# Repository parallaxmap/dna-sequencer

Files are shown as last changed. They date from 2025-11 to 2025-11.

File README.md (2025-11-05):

# DNA Sequencer
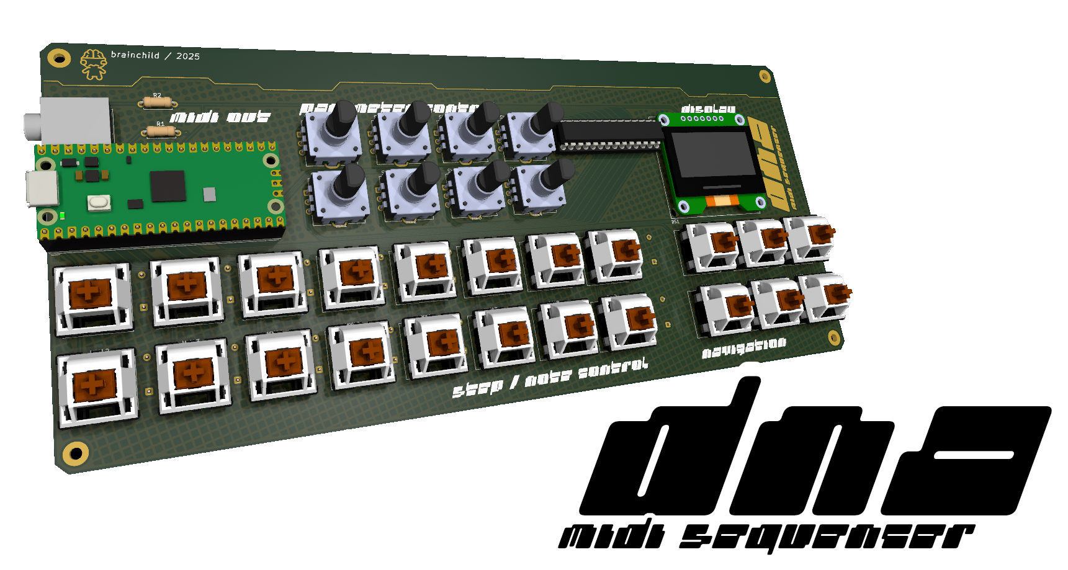
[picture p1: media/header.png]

A flexible MIDI sequencer powered by a Raspberry Pi Pico 2 (RP2350), inspired by sequencers found in the Korg Volca and Elektron boxes. Aims to be accessible, affordable, repurposable, and expandable.

## Current features
- RPi Pico 2 microcontroller, the brains of the sequencer
- MIDI output via 3.5mm TRS, or USB
- 16 keys for step editing, note input, or other custom macros
- 6 keys for navigation (get ready to menu dive!)
- 8 incremental encoders for CC/parameter adjustment and macros
- 128x64 1.3" OLED display
- All components are through-hole for easy soldering, and readily available

## Planned features
- 8 polyphonic tracks with different modes to facilitate various types of sequencing (e.g drum, chord, arp, euclidian, etc etc), can be assigned to any 16 MIDI channels
- 64 step sequencer with the ability to sequence 8 CC parameters, variable length, microtiming, and randomization/generation features
- 16 patterns with chaining

## Why'd you make this?
Currently the options for standalone hardware MIDI sequencers are either budget sequencers that do not have a vast featureset and, at least to myself, were limiting in terms of potential creativity, or more feature rich sequencers which cost a couple arms and legs. I wanted to make a device that would help bridge the gap between those two mountains and leverage the power of DIY & open source in order to create an accessible, affordable, repurposable, and expandable hardware sequencer. Additionally, this project serves as my first 100% serious hardware project, so all of the processes I learn throughout the journey of creating this device will be invaluable to me and whatever future endeavours lie before me... learning is fun!

## Images/Videos
PCB
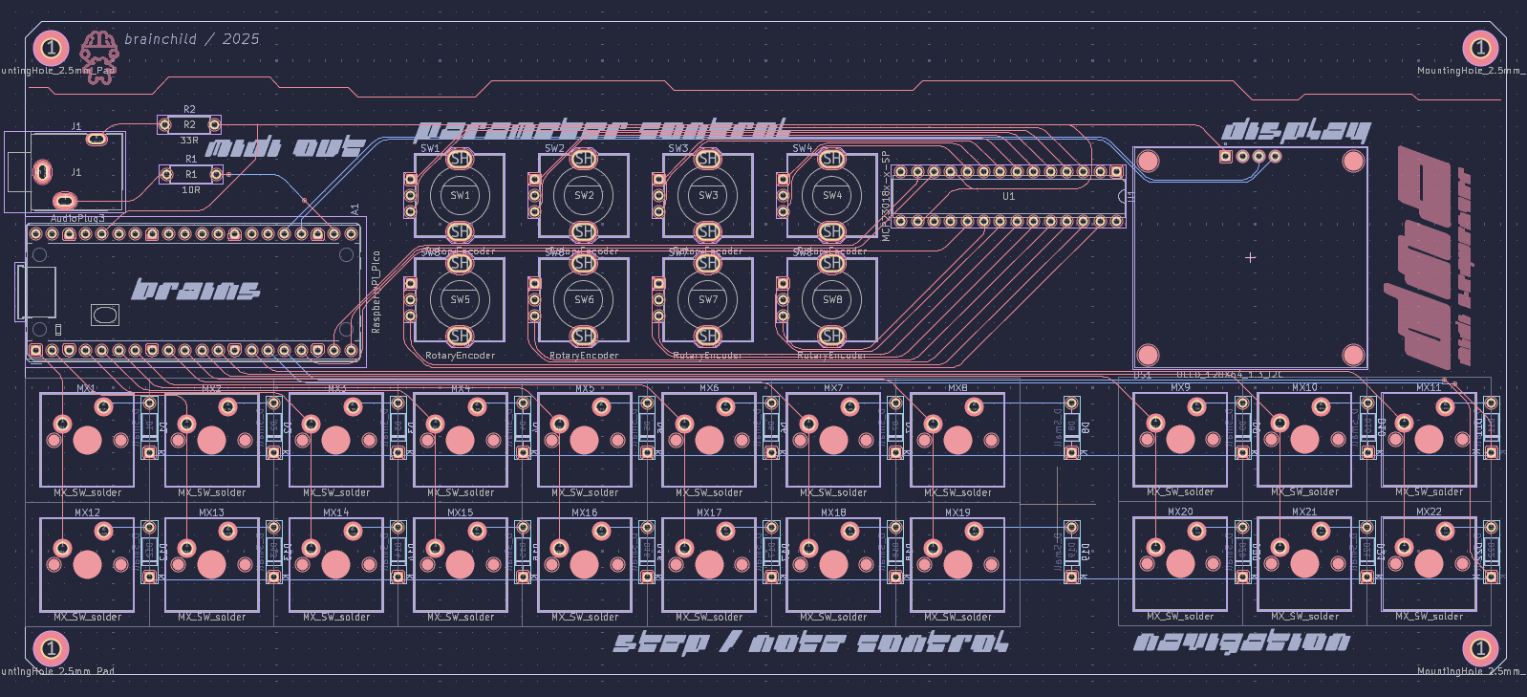
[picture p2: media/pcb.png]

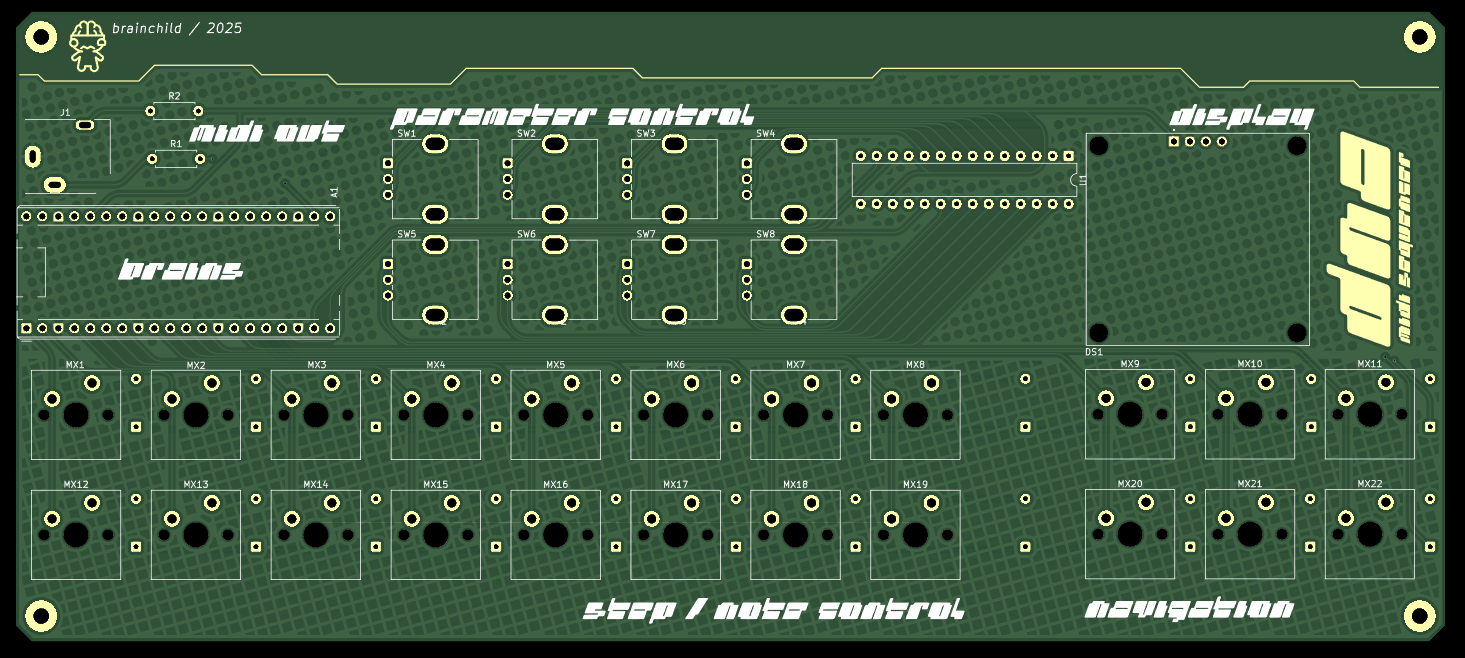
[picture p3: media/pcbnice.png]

Schematic
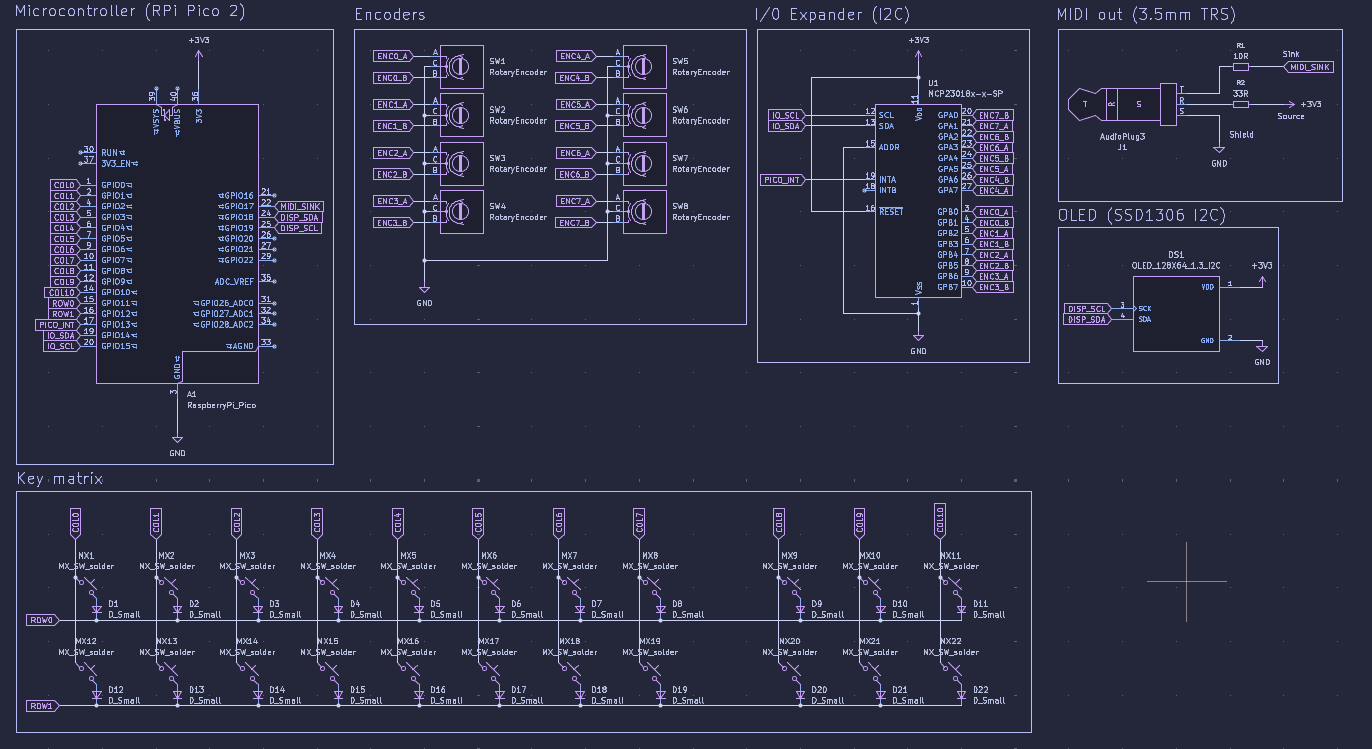
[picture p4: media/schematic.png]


## Bill of Materials

Choice of keycaps is up to you, as long as they're compatible with Cherry MX. You will also need a Micro USB cable for power and USB MIDI, and a 3.5 TRS to DIN converter for regular MIDI

|Item |Description |Quantity|Unit Price ($)|Total Price ($)|URL |Total |
|---|---|---|---|---|---|---|
|MBB02070C1009FCT00 |10 Ohm resistor |5 |$0.1346 |$0.6730 |https://www.lcsc.com/product-detail/C1364448.html |$0.6730|
|MBB02070C3309FCT00 |33 Ohm resistor |5 |$0.0748 |$0.3740 |https://www.lcsc.com/product-detail/C1366513.html |$1.05 |
|MCP23017-E/SP |I/O expander (I2C) |1 |$2.8158 |$2.8158 |https://www.lcsc.com/product-detail/C4992459.html |$3.86 |
|PEC12R-4120F-S0012 |Rotary encoder |8 |$1.8791 |$15.0328 |https://www.lcsc.com/product-detail/C143801.html |$18.90|
|SJ1-3533NG |3.5mm TRS jack |1 |$1.6565 |$1.6565 |https://www.lcsc.com/product-detail/C4992459.html |$20.55|
|KH-2.54FH-1X20P-H8.5 |Socket (20 pins) |5 |$0.1722 |$0.8610 |https://www.lcsc.com/product-detail/C2905423.html |$21.41|
| PH2.54-1X20P-H25 |Header (20 pins) |5 |$0.0488 |$0.2440 |https://www.lcsc.com/product-detail/C42431804.html |$21.66|
|IC-28P |DIP socket |17 |$0.0510 |$0.8670 |https://www.lcsc.com/product-detail/C5289491.html |$22.52|
|M3x10+6Cu |Standoffs |10 |$0.0387 |$0.3870 |https://www.lcsc.com/product-detail/C551322.html |$22.91|
|hexagon NUT M3 |Hex nut |100 |$0.0017 |$0.1700 |https://www.lcsc.com/product-detail/C133377.html |$23.08|
|1N4148 |Diodes |50 |$0.0116 |$0.5800 |https://www.lcsc.com/product-detail/C402212.html |$23.66|
|SH1106 |OLED display module |1 |$3.6800 |$3.6800 |https://www.aliexpress.com/item/1005006072386746.html|$27.34|
|MIDI DIN to 3.5mm TRS  |DIN/TRS converter cable |1 |$8.2000 |$8.2000 |https://www.aliexpress.com/item/1005009365055437.html|$35.54|
|Ugreen Micro USB Cable |Micro USB for microcontroller|1 |$2.6900 |$2.6900 |https://www.aliexpress.com/item/32391749504.html |$38.23|
|XDA Profile PBT Keycaps|1U keycaps (30pcs) |1 |$5.4100 |$5.4100 |https://www.aliexpress.com/item/1005005514406952.html|$43.64|
|11mm Potentiometer Knob|Knobs for encoders (10pcs) |1 |$2.1000 |$2.1000 |https://www.aliexpress.com/item/1005003991686731.html|$45.74|
|Gateron Switches KS9 |Key switch (30pcs) |1 |$12.9500 |$12.9500 |https://www.aliexpress.com/item/1005007474127225.html|$58.69|
|RPI Pico 2 |Microcontroller |1 |$8.9800 |$8.9800 |https://www.aliexpress.com/item/1005008201547951.html|$67.67|
|JLCPCB |PCB x 5 and shipping costs |1 |$24.42 |$24.42 | |$92.09|
|LCSC |LCSC shipping costs |1 |$8.84 |$8.84 | |$100.93|

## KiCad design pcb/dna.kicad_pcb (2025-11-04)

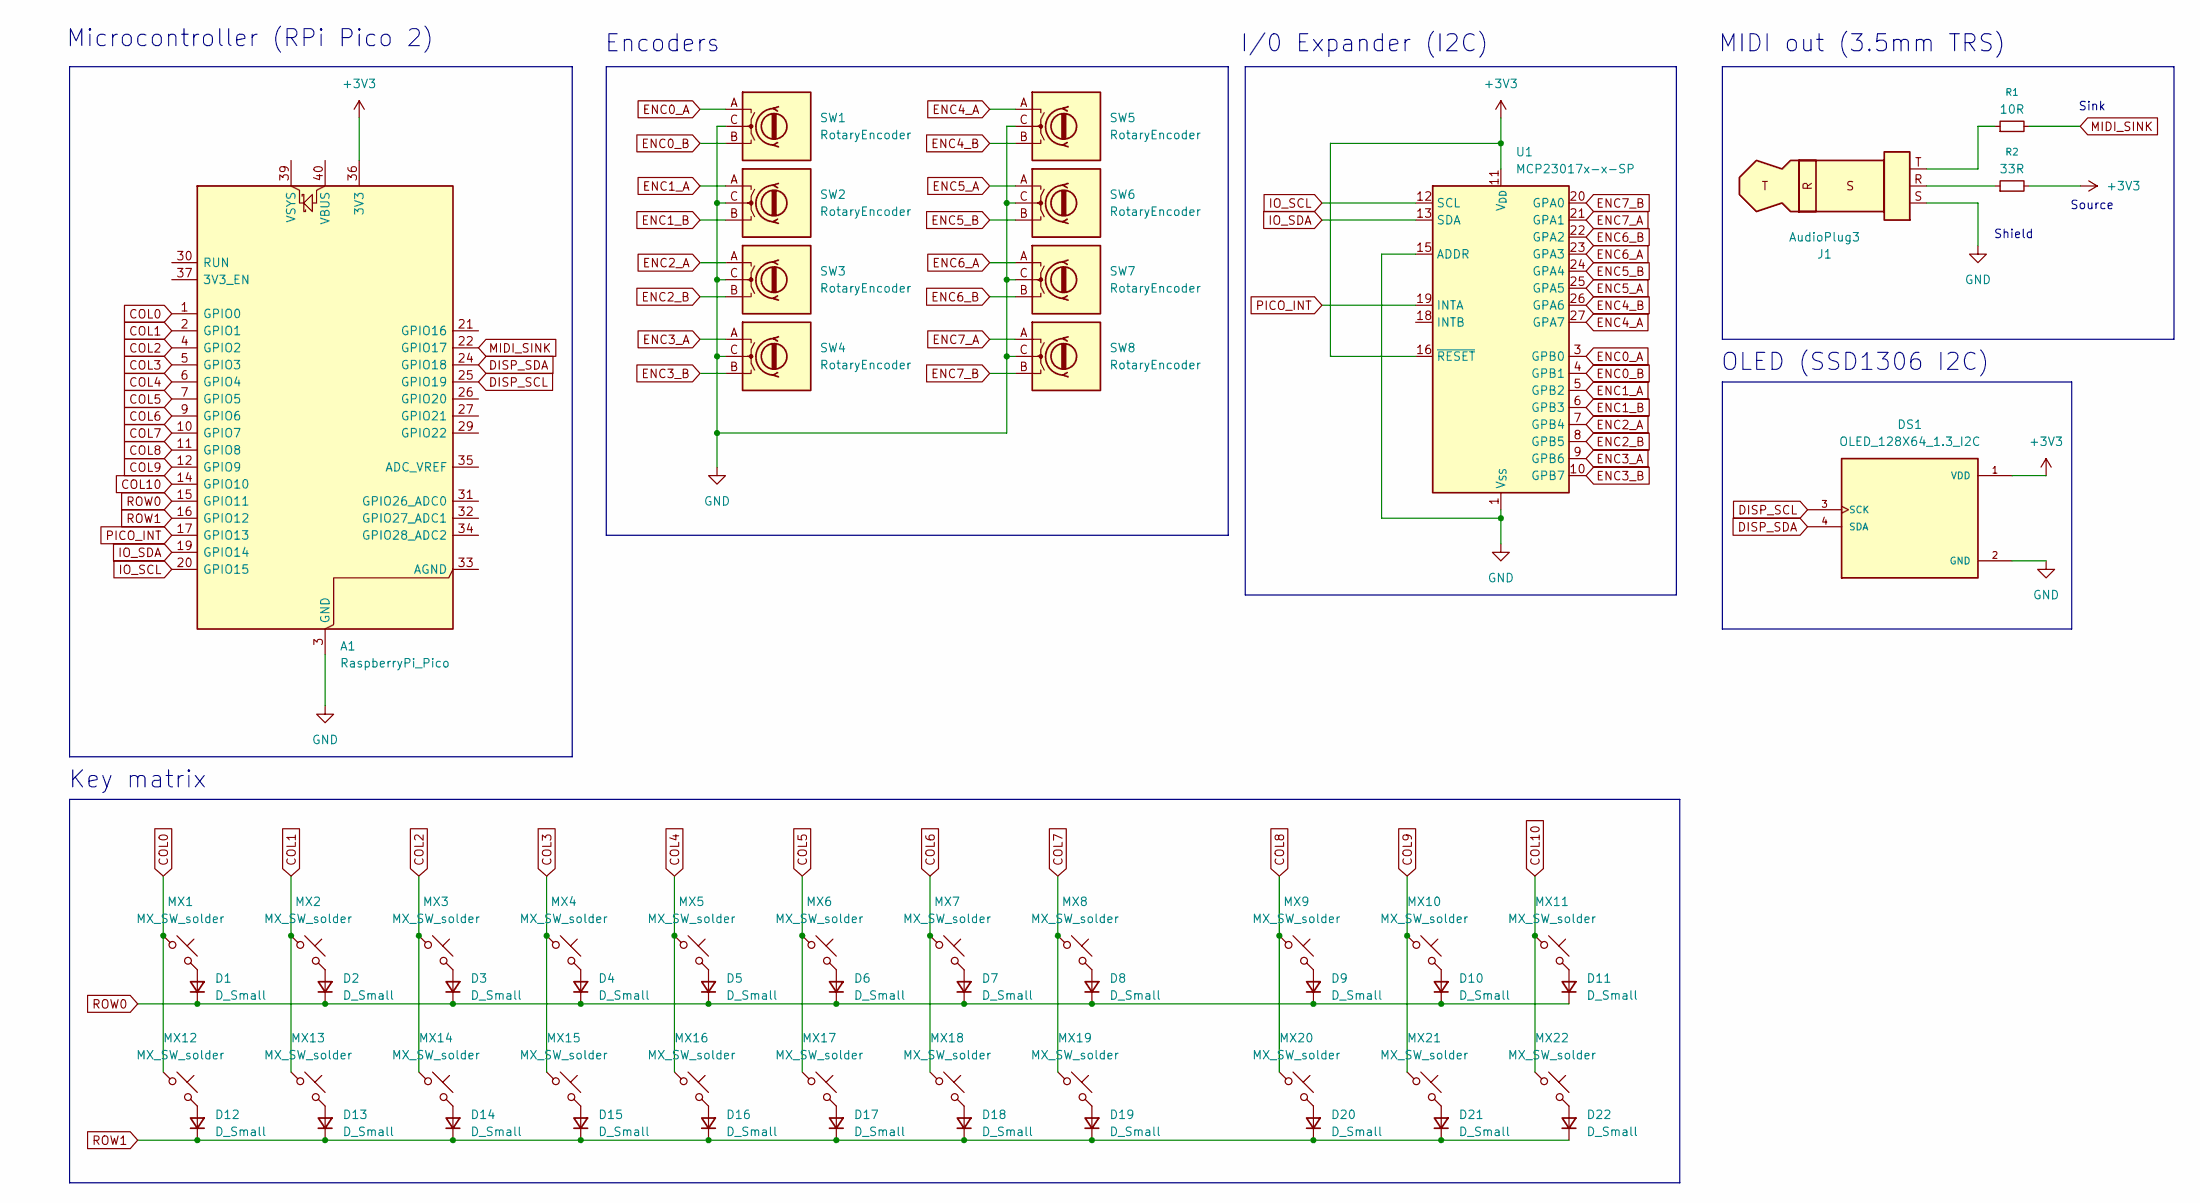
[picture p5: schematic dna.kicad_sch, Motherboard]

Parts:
A1: RaspberryPi_Pico; RaspberryPi_Pico_Common_THT
D1, D2, D3, D4, D5, D6, D7, D8, D9, D10, D11, D12, D13, D14, D15, D16, D17, D18, D19, D20, D21, D22: D_Small; D_DO-35_SOD27_P7.62mm_Horizontal
DS1: OLED_128X64_1.3_I2C; LCD_OLED_128X64_1.3_I2C; PARTREV NA
J1: AudioPlug3; Jack_3.5mm_CUI_SJ1-3533NG_Horizontal_CircularHoles
MX1, MX2, MX3, MX4, MX5, MX6, MX7, MX8, MX9, MX10, MX11, MX12, MX13, MX14, MX15, MX16, MX17, MX18, MX19, MX20, MX21, MX22: MX_SW_solder; SW_Cherry_MX_PCB_1.00u
R1: 10R; R_Axial_DIN0207_L6.3mm_D2.5mm_P7.62mm_Horizontal
R2: 33R; R_Axial_DIN0207_L6.3mm_D2.5mm_P7.62mm_Horizontal
SW1, SW2, SW3, SW4, SW5, SW6, SW7, SW8: RotaryEncoder; RotaryEncoder_Bourns_Vertical_PEC12R-3x17F-Sxxxx
U1: MCP23017x-x-SP; DIP-28_W7.62mm

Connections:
+3V3: A1.36 (3V3), DS1.1 (VDD), R2.2, U1.11 (V_{DD}), U1.16 (~RESET)
COL0: A1.1 (GPIO0), MX1.1, MX12.1
COL1: A1.2 (GPIO1), MX2.1, MX13.1
COL2: A1.4 (GPIO2), MX3.1, MX14.1
COL3: A1.5 (GPIO3), MX4.1, MX15.1
COL4: A1.6 (GPIO4), MX5.1, MX16.1
COL5: A1.7 (GPIO5), MX6.1, MX17.1
COL6: A1.9 (GPIO6), MX7.1, MX18.1
COL7: A1.10 (GPIO7), MX8.1, MX19.1
COL8: A1.11 (GPIO8), MX9.1, MX20.1
COL9: A1.12 (GPIO9), MX10.1, MX21.1
COL10: A1.14 (GPIO10), MX11.1, MX22.1
DISP_SCL: A1.25 (GPIO19), DS1.3 (SCK)
DISP_SDA: A1.24 (GPIO18), DS1.4 (SDA)
ENC0_A: SW1.A, U1.3 (GPB0)
ENC0_B: SW1.B, U1.4 (GPB1)
ENC1_A: SW2.A, U1.5 (GPB2)
ENC1_B: SW2.B, U1.6 (GPB3)
ENC2_A: SW3.A, U1.7 (GPB4)
ENC2_B: SW3.B, U1.8 (GPB5)
ENC3_A: SW4.A, U1.9 (GPB6)
ENC3_B: SW4.B, U1.10 (GPB7)
ENC4_A: SW5.A, U1.27 (GPA7)
ENC4_B: SW5.B, U1.26 (GPA6)
ENC5_A: SW6.A, U1.25 (GPA5)
ENC5_B: SW6.B, U1.24 (GPA4)
ENC6_A: SW7.A, U1.23 (GPA3)
ENC6_B: SW7.B, U1.22 (GPA2)
ENC7_A: SW8.A, U1.21 (GPA1)
ENC7_B: SW8.B, U1.20 (GPA0)
GND: A1.3 (GND), A1.8 (GND), A1.13 (GND), A1.18 (GND), A1.23 (GND), A1.28 (GND), A1.38 (GND), DS1.2 (GND), J1.S, SW1.C, SW2.C, SW3.C, SW4.C, SW5.C, SW6.C, SW7.C, SW8.C, U1.1 (V_{SS}), U1.15 (ADDR)
IO_SCL: A1.20 (GPIO15), U1.12 (SCL)
IO_SDA: A1.19 (GPIO14), U1.13 (SDA)
MIDI_SINK: A1.22 (GPIO17), R1.2
unnamed: D1.2 (A), MX1.2
unnamed: D2.2 (A), MX2.2
unnamed: D3.2 (A), MX3.2
unnamed: D4.2 (A), MX4.2
unnamed: D5.2 (A), MX5.2
unnamed: D6.2 (A), MX6.2
unnamed: D7.2 (A), MX7.2
unnamed: D8.2 (A), MX8.2
unnamed: D9.2 (A), MX9.2
unnamed: D10.2 (A), MX10.2
unnamed: D11.2 (A), MX11.2
unnamed: D12.2 (A), MX12.2
unnamed: D13.2 (A), MX13.2
unnamed: D14.2 (A), MX14.2
unnamed: D15.2 (A), MX15.2
unnamed: D16.2 (A), MX16.2
unnamed: D17.2 (A), MX17.2
unnamed: D18.2 (A), MX18.2
unnamed: D19.2 (A), MX19.2
unnamed: D20.2 (A), MX20.2
unnamed: D21.2 (A), MX21.2
unnamed: D22.2 (A), MX22.2
unnamed: J1.R, R2.1
unnamed: J1.T, R1.1
PICO_INT: A1.17 (GPIO13), U1.19 (INTA)
ROW0: A1.15 (GPIO11), D1.1 (K), D2.1 (K), D3.1 (K), D4.1 (K), D5.1 (K), D6.1 (K), D7.1 (K), D8.1 (K), D9.1 (K), D10.1 (K), D11.1 (K)
ROW1: A1.16 (GPIO12), D12.1 (K), D13.1 (K), D14.1 (K), D15.1 (K), D16.1 (K), D17.1 (K), D18.1 (K), D19.1 (K), D20.1 (K), D21.1 (K), D22.1 (K)

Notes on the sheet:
Key matrix
Sink
I/0 Expander (I2C)
Source
Microcontroller (RPi Pico 2)
MIDI out (3.5mm TRS)
OLED (SSD1306 I2C)
Encoders
Shield

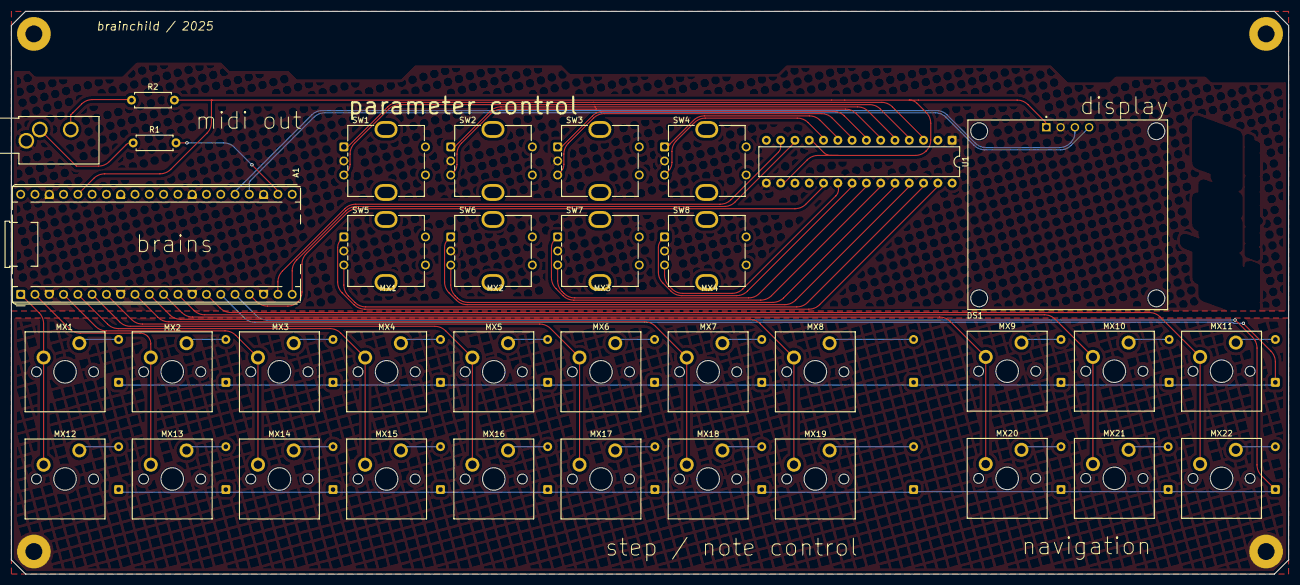
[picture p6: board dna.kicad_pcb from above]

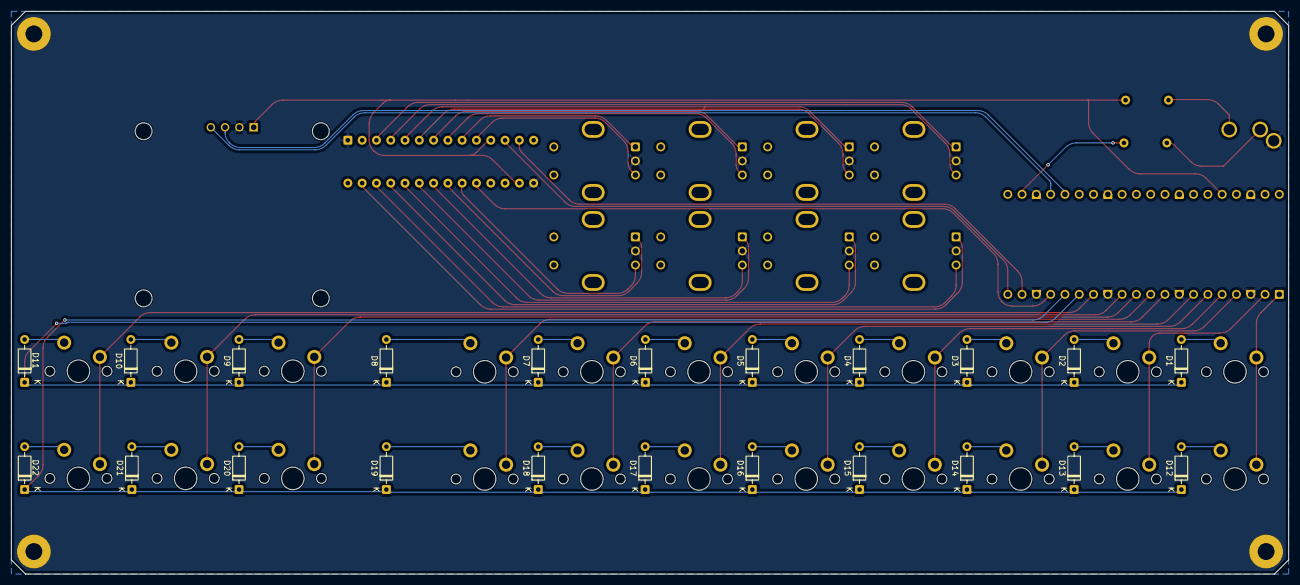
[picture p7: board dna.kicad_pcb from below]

Board: 2 copper layers, 227.0 x 100.0 mm, 58 parts (22 on the bottom side), 61 nets.

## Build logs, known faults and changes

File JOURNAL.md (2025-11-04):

<!--
  ===================    !!READ THIS NOTICE!!   ====================
  DO NOT edit this file manually. Your changes WILL BE OVERWRITTEN!
  This journal is auto generated and updated by Hack Club Blueprint.
  To edit this file, please edit your journal entries on Blueprint.
  ==================================================================
-->

## 10/29/2025 - Project goals & concept sketch  

Not really sure how to introduce this first section, so I'll just lay down the goals that I've given myself for this project:
- Create an affordable MIDI sequencer which doesn't skimp on features
- Easy to build, customize, and repurpose if necessary
- Improve on my ability to build, prototype, ship, and iterate on a project
- Get a deeper understanding of MIDI and how it is implemented

For the sequencer's features, after spending some time looking at the features that other synthesizers/sequencers provide and plucking the ideas that I liked the most (whilst also being wary of both computational limits and potential cost savings), I came up with this feature set:
- 8 polyphonic tracks with different modes to facilitate various types of sequencing (e.g drum, chord, arp, euclidian, etc etc), can be assigned to any 16 MIDI channels
- 64 step sequencer with the ability to sequence 8 CC parameters, variable length, microtiming, and randomization/generation features
- 8 parameter macros for performance
- 16 patterns with chaining
- MIDI USB/TRS out

Finally, here's an initial sketch of the design I had in mind for the sequencer:



## 10/30/2025 - Creating initial schematic  

I have completed the majority of the schematic for the main PCB, the only part I have left is to figure out what display module I would like to use and get a KiCad footprint/symbol for it.

Along the way, I had to learn how to create a key/button matrix, how to implement MIDI output electrically, and how to connect a large amount of digital inputs into a microcontroller using an I/O expander, using a lot of intense internet searching, and occasionally asking a few buddies that know more than I do for directions. :)

It was time consuming... but was worth it for the knowledge gained and the satisfaction of a finished task! (for now...)



## 10/31/2025 - PCB routing, revised schematics and decoration  

I spent about 8 hours all together (re)routing the PCB, finding the appropriate footprints and models for components, and re-configuring the schematics in order to facilitate a more efficient PCB design. Here are some images of the final result, I'm quite proud of it personally...



It's intended to be used as a bare PCB (ideally with standoffs), but there are mounting holes that could potentially be used to mount it within an enclosure if you so wish. A good chunk of those 8 hours were spent on 2 previous PCB designs that were abandoned due to the routing being, for lack of a better word, terrible... third time's the charm, as they say :)

Most of the components used here should be able to easily obtained as they are very common electronic components, but I'll have to double check that when it comes to creating the BOM.

After I completed the main PCB rotuing/design, I moved onto adding some small decorations and labels across the design to make it pop out a bit! Although, I was already so exhausted after 3 attempts of routing that I wasn't too tempted to try something extravagant yet...  

## 11/1/2025 12 AM - SMD to Through hole components  

Converted all the previously SMD components on my PCB to through hole components, as this would give me more time to spend actually building the project, gathering tickets, and reduce costs & complexity as I wouldn't (or anybody else building this project) have to do SMD soldering by hand or get PCBA!



## 11/1/2025 3 AM - Creating parts list/BOM  

I spent a couple hours looking at all the components I have been using on my PCB and compiling them all into a BOM. All parts are sourced from DigiKey, except for the OLED display module + MIDI DIN/TRS converter and Micro USB connector neccecary for testing, which was sourced from AliExpress as these are significantly cheaper over there and/or cannot be ordered from DigiKey.


## 11/1/2025 3 PM - Creating Gerbers & models, and tidying up the repository  

Coming up to the final stretch of tasks before getting ready to ship, so far today I have spent the time learning how to create Gerber files from KiCad for fabrication, as well as the .wrl model required by the guidelines. To test to make sure that my Gerber files were all correct and ready to be shipped, I dragged it into JLCPCB, and it all seems to have loaded in correctly (thankfully!)

Additionally, I spent some time writing some more details about the project in the README, as well as adding pictures of the PCB, schematic, and a nice 3D render from KiCad as the header image. I had to spend some time to figure out how to convert my BOM to a Markdown table, and eventually found [a website](https://tabletomarkdown.com/convert-spreadsheet-to-markdown/) that allows me to convert my original LibreOffice Calc file (there is still a BOM.csv within the repository) into a formatted Markdown table.  

## 11/2/2025 - Final task! (for now)  

The initial test firmware is completed! I spent some time researching how to program the Pico for the parts that I have on the board, initially I tried using regular MicroPython and implementing a lot of the stuff manually, but abandoned that idea after some time as I knew it would take way too long than neccecary (and i was sure there was an easier way...)

Eventually, I stumbled upon CircuitPython, which is an alternative to MicroPython that provided a lot of convenience tools like key matrix input, a library for the type of display i am using, etc etc...



The final code (this is not the entire code in the picture) should, if everything is correct, allow you to play a scale of notes on the 16 step keys, display information about what key is pressed and the note being output on the display, and output those notes via the TRS jack!  

## 11/3/2025 - ...nevermind! PCB visual overhaul  

Ended up having some issues that I am currently in the process of resolving regarding verification for submission (shoutouts, they've been very quick to respond and helpful :]), so I decided to at least spend that extra time doing some final touch ups to the look of the PCB, since my initial design was admittedly quite rushed and I didn't feel it fit the "vibe" I was going for. really proud of this!


## 11/4/2025 12 AM - Uploaded new assets, gerbers and models based on new design  

The GitHub page should be fully ready now! I'm confident that I've covered all bases, and I spent some time re-exporting some things and creating new graphics to ensure that the repository is fully up to date and ready to ship. Let's just hope it's smooth sailing from here! :)
header

## 11/4/2025 1 AM - Forgot to add diodes to BOM, oops!  

Basically what the title says, don't know how I didn't notice the other times I checked but it's an important point to always triple check everything before it gets sent off... luckily the price of the diodes is so cheap so there shouldn't be any adjustments necessary! Silly mistake on my part... but at least it's fixed!!!


## 11/4/2025 10 PM - Refactoring BOM  



Spent some time refactoring the BOM with the suggestions my reviewer gave, only shaved off about $5.75, but a lot of the components were much cheaper on LCSC - with the caveat of minimum quantites, but either way that means I'm getting much better value for my money. Switches and microcontroller will now be ordered from AliExpress.  

## 11/4/2025 11 PM - Part/BOM adjustment, PCB adjustment  

Had to change a few parts in the BOM as they were not readily available, and thus had to make some very minor changes to the PCB. All of it has been checked and the PCB has been approved by JLCPCB.


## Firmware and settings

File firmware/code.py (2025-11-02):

# this code is a hunk of crap but should be ok for testing if the thing works lol
# circuitpython required!

import board
import busio
import time
from adafruit_matrixkeypad import Matrix_Keypad
import digitalio
from adafruit_ssd1306 import SSD1306_I2C
from PIL import Image, ImageDraw, ImageFont

# super awesome display setup
i2c = busio.I2C(board.GP18, board.GP19)  # SDA, SCL
WIDTH = 128
HEIGHT = 64
oled = SSD1306_I2C(WIDTH, HEIGHT, i2c)

# clear display
oled.fill(0)
oled.show()

image = Image.new("1", (WIDTH, HEIGHT))
draw = ImageDraw.Draw(image)
font = ImageFont.load_default()

uart = busio.UART(board.GP17, board.GP16, baudrate=31250)

def midi_note_on(note, velocity=127, channel=1):
    uart.write(bytes([0x90 | channel, note, velocity]))

def midi_note_off(note, velocity=0, channel=1):
    uart.write(bytes([0x80 | channel, note, velocity]))

rows = [board.GP0, board.GP1]
cols = [board.GP2, board.GP3, board.GP4, board.GP5,
        board.GP6, board.GP7, board.GP8, board.GP9]

keypad = Matrix_Keypad(rows, cols)

notes = [
    60, 61, 62, 63, 64, 65, 66, 67,  # row 0
    68, 69, 70, 71, 72, 73, 74, 75   # row 1
]

key_states = [False] * 16

def update_display(key_idx=None):
    draw.rectangle((0, 0, WIDTH, HEIGHT), outline=0, fill=0)  # clear screen
    if key_idx is not None:
        draw.text((0, 0), f"key: {key_idx}", font=font, fill=255)
        draw.text((0, 16), f"note: {notes[key_idx]}", font=font, fill=255)
    else:
        draw.text((0, 0), "no key pressed", font=font, fill=255)
    oled.image(image)
    oled.show()

while True:
    keys = keypad.pressed_keys  # list of (row, col) tuples
    any_key_pressed = False

    for r in range(len(rows)):
        for c in range(len(cols)):
            key_idx = r * len(cols) + c
            pressed = (r, c) in keys
            if pressed and not key_states[key_idx]:
                midi_note_on(notes[key_idx])
                key_states[key_idx] = True
                update_display(key_idx)
                any_key_pressed = True
            elif not pressed and key_states[key_idx]:
                midi_note_off(notes[key_idx])
                key_states[key_idx] = False

    if not any_key_pressed:
        update_display(None)

    time.sleep(0.01)  # small debounce

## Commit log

2025-10-31 Add KiCad source files
    [dna.kicad_pcb, dna.kicad_sch]
2025-11-01 Update PCB source files
    [dna.kicad_pcb, dna.kicad_sch]
2025-11-01 Add BOM
    [bom.csv]
